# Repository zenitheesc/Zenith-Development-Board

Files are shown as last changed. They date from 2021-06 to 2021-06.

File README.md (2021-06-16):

<h1 align="center" style="color:white; background-color:black">Zenith Development Board</h1>
<h4 align="center">A Development Board based on STM32F103C8T6</h4>

<p align="center">
	<a href="http://zenith.eesc.usp.br/">
    
    </a>
    <a href="https://eesc.usp.br/">
    
    </a>
    <a href="https://github.com/${{ env.REPOSITORY_FULL_NAME }}/blob/main/LICENSE">
    
    </a>
    <a href="https://github.com/${{ env.REPOSITORY_FULL_NAME }}/issues">
    
    </a>
    <a href="https://github.com/${{ env.REPOSITORY_FULL_NAME }}/commits/main">
    
    </a>
    <a href="https://github.com/${{ env.REPOSITORY_FULL_NAME }}/graphs/contributors">
    
    </a>
    <a href="https://github.com/${{ env.REPOSITORY_FULL_NAME }}/commits/main">
    
    </a>
    <a href="https://github.com/${{ env.REPOSITORY_FULL_NAME }}/issues">
    
    </a>
    <a href="https://github.com/${{ env.REPOSITORY_FULL_NAME }}/pulls">
    
    </a>
</p>

<p align="center">
    <a href="#environment-and-tools">Environment and Tools</a> •
    <a href="#how-to-contribute">How to contribute?</a> 
</p>

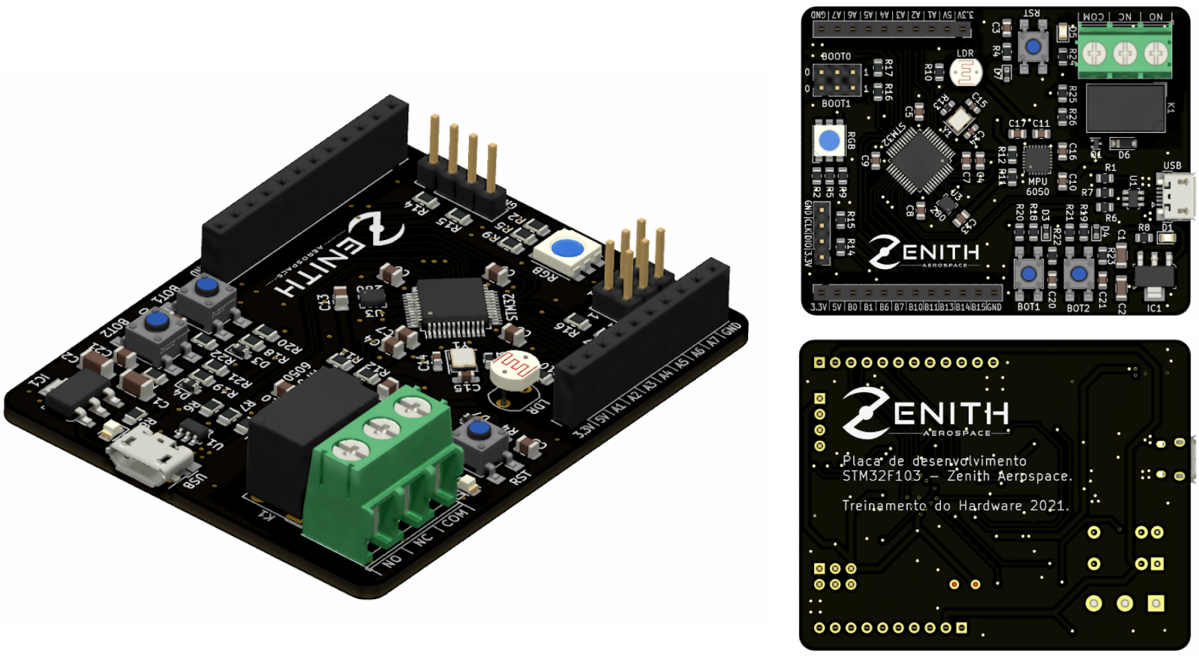
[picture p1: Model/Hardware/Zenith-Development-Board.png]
Zenith-Development-Board


## Environment and tools

This board was developed using [KiCad](https://www.kicad.org/) with native components.

## How to contribute

Fork your personal Git and add your hardware and software version in the "Development" folder following the Issues listed in the repository.

---

<p align="center">
    <a href="http://zenith.eesc.usp.br">
    
    </a> 
    <a href="https://www.facebook.com/zenitheesc">
    
    </a> 
    <a href="https://www.instagram.com/zenith_eesc/">
    
    </a>

</p>
<p align = "center">
<a href="zenith.eesc@gmail.com">zenith.eesc@gmail.com</a>
</p>

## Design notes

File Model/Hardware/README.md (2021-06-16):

# Zenith Development Board

Development board based on the STM32F103C8T6 developed to introduce the group members to circuits similar to those that can be used in the projects, including light, acceleration, rotation, pressure and temperature sensors, as well as actuators such as Mosfets, Relays and Leds.

# Schematic

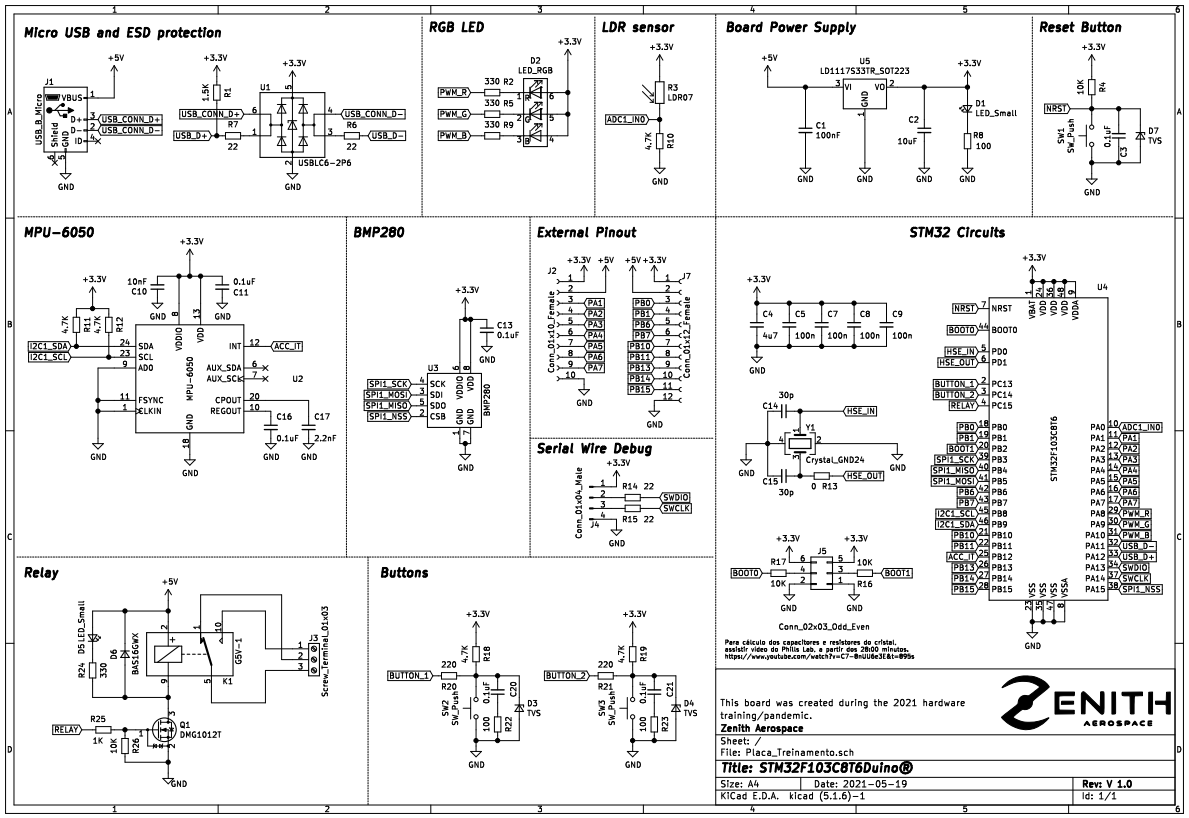
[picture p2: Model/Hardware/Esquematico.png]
Schematic


# Layout

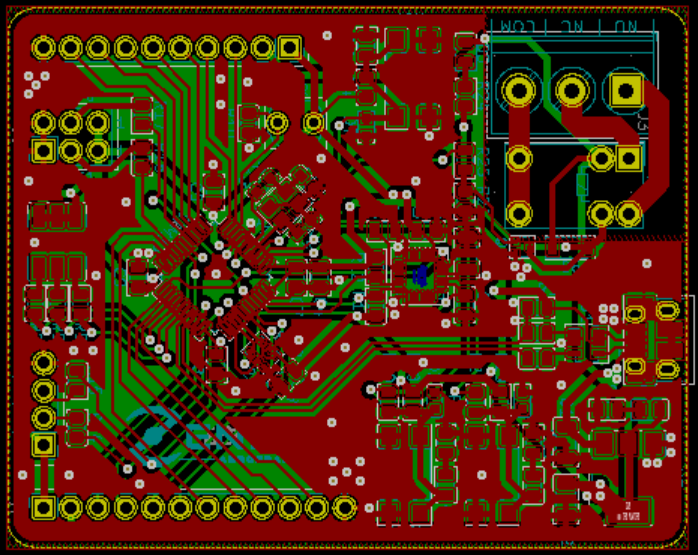
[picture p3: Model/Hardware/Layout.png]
Layout


# B.O.M.
|Component|Amount|Description|
|--|--|--|
|STM32F103C8T6|1|Microcontroller|
|Crystal|1|16MHz|
|MPU-6050|1|Accelerometer and Gyroscope|
|BMP280|1|Pressure and temperature sensor|
|LDR|1|Light Dependent Resistor|
|RGB-LED|1|Led SMD|
|Button|2|Push button|
|ESD suppressor|2|652-CGA0603MLC-12E|
|Micro USB|1|Micro USB connector|
|ESD Protection|1|USBLC6-4SC6Y|
|Linear regulator|1|LD1117S33TR|
|Rele|1|G5V-1-DC5|
|Mosfet|1|DMG1012T-7|

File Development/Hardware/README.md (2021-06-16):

# [Circuit name]

[Description]

# Schematic

[Figure]

# Layout

[Figure]

# Tests

## Simulation

[Description]

## Prototyping

[Description]

## Validation

[Description]

# B.O.M.
|Component|Amount|Description|
|--|--|--|
|X|0|x|
|Y|0|y|
|Z|0|z|

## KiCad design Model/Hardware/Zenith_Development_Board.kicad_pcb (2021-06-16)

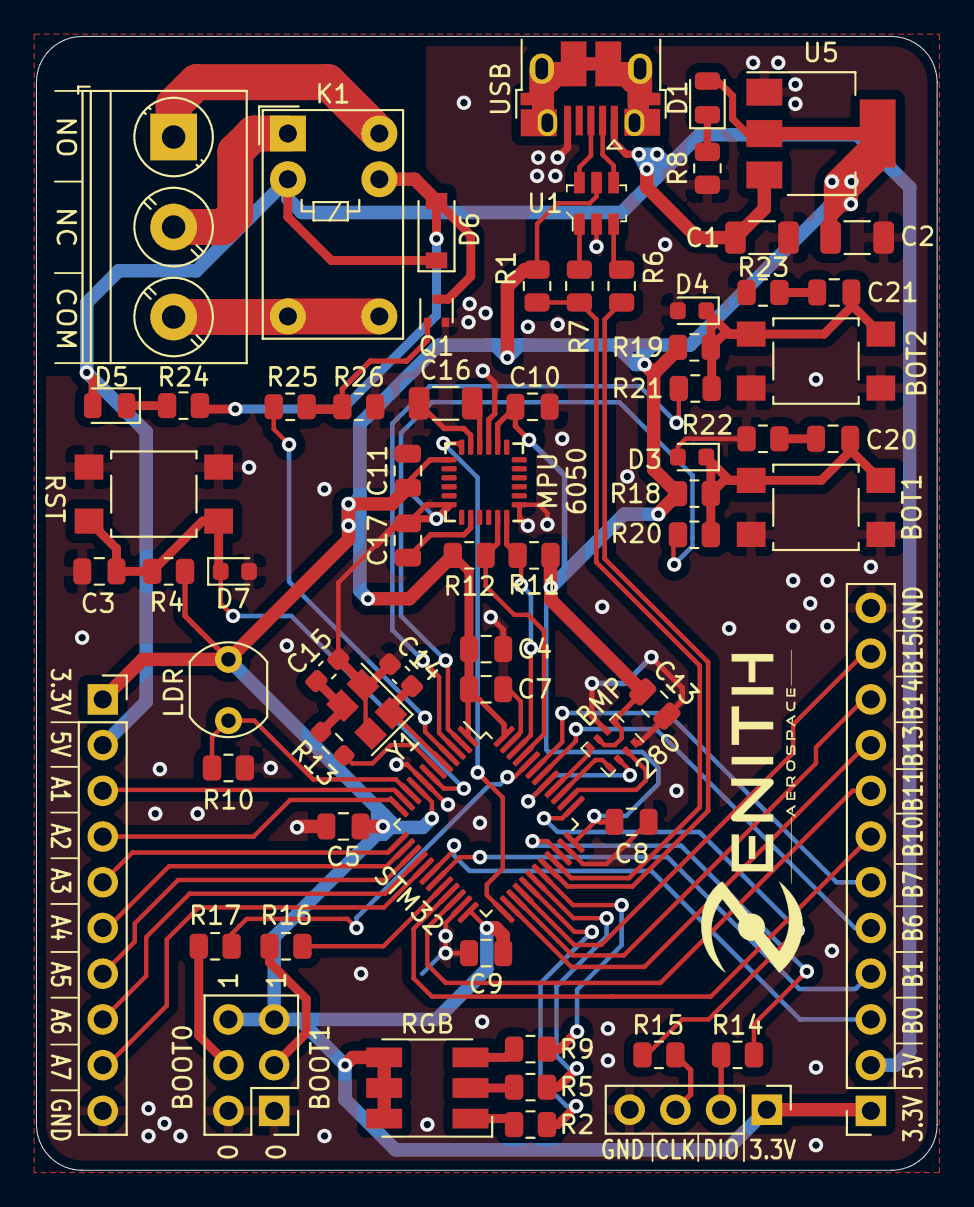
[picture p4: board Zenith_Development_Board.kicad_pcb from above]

Board: 2 copper layers, 50.0 x 63.0 mm, 67 parts (0 on the bottom side), 67 nets.

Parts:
C1: 100nF; C_1206_3216Metric
C2: 10uF; C_1206_3216Metric
C3, C11, C13, C20, C21: 0.1uF; C_0805_2012Metric
C4: 4u7; C_0805_2012Metric
C5, C7, C8, C9: 100n; C_0805_2012Metric
C10: 10nF; C_0805_2012Metric
C14, C15: 30p; C_0603_1608Metric_Pad1.08x0.95mm_HandSolder
C16: 0.1uF; C_1206_3216Metric
C17: 2.2nF; C_0805_2012Metric
D1, D5: LED_Small; LED_0805_2012Metric
D2: LED_RGB; LED_RGB_5050-6
D3, D4, D7: TVS; D_0603_1608Metric
D6: BAS16GWX; D_SOD-123
J1: USB_B_Micro; USB_Micro-B_Amphenol_10103594-0001LF_Horizontal
J2: Conn_01x10_Female; PinSocket_1x10_P2.54mm_Vertical
J3: Screw_Terminal_01x03; TerminalBlock_Phoenix_PT-1,5-3-5.0-H_1x03_P5.00mm_Horizontal
J4: Conn_01x04_Male; PinHeader_1x04_P2.54mm_Vertical
J5: Conn_02x03_Odd_Even; PinHeader_2x03_P2.54mm_Vertical
J7: Conn_01x12_Female; PinSocket_1x12_P2.54mm_Vertical
K1: G5V-1; Relay_SPDT_Omron_G5V-1
Q1: DMG1012T; SOT-523
R1: 1.5K; R_0805_2012Metric
R2, R5, R9, R24: 330; R_0805_2012Metric
R3: LDR07; R_LDR_5.1x4.3mm_P3.4mm_Vertical
R4, R16, R17, R26: 10K; R_0805_2012Metric
R6, R7, R14, R15: 22; R_0805_2012Metric
R8, R22, R23: 100; R_0805_2012Metric
R10, R11, R12, R18, R19: 4.7K; R_0805_2012Metric
R13: 0; R_0603_1608Metric_Pad0.98x0.95mm_HandSolder
R20, R21: 220; R_0805_2012Metric
R25: 1K; R_0805_2012Metric
SW1, SW2, SW3: SW_Push; SW_SPST_TL3305A
U1: USBLC6-2P6; SOT23-6L
U2: MPU-6050; InvenSense_QFN-24_4x4mm_P0.5mm
U3: BMP280; Bosch_LGA-8_2x2.5mm_P0.65mm_ClockwisePinNumbering
U4: STM32F103C8T6; LQFP-48_7x7mm_P0.5mm
U5: LD1117S33TR_SOT223; SOT-223-3_TabPin2
Y1: Crystal_GND24; Crystal_SMD_SeikoEpson_FA238-4Pin_3.2x2.5mm

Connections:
+3V3: C2.1, C4.1, C5.1, C7.1, C8.1, C9.1, C10.2, C11.1, C13.1, D1.2, D2.4, D2.5, D2.6, J2.1, J4.1, J5.5, J5.6, J7.1, R1.2, R3.1, R4.1, R11.1, R12.1, R18.1, R19.1, U1.5, U2.8, U2.13, U3.6, U3.8, U4.1, U4.9, U4.24, U4.36, U4.48, U5.2
+5V: C1.1, D5.2, D6.1, J1.1, J2.2, J7.2, K1.2, U5.3
ACC_IT: U2.12, U4.25
ADC1_IN0: R3.2, R10.1, U4.10
BOOT0: R17.1, U4.44
BOOT1: R16.1, U4.20
BUTTON_1: R20.2, U4.2
BUTTON_2: R21.2, U4.3
GND: C1.2, C2.2, C3.1, C4.2, C5.2, C7.2, C8.2, C9.2, C10.1, C11.2, C13.2, C14.2, C15.2, C16.2, C17.2, D3.2, D4.2, D7.2, J1.5, J2.10, J4.4, J5.1, J5.2, J7.12, Q1.2, R8.1, R10.2, R22.2, R23.2, R26.2, SW1.2, SW2.2, SW3.2, U1.2, U2.1, U2.9, U2.11, U2.18, U3.1, U3.7, U4.8, U4.23, U4.35, U4.47, U5.1, Y1.2, Y1.4
HSE_IN: C14.1, U4.5, Y1.1
HSE_OUT: R13.2, U4.6
I2C1_SCL: R12.2, U2.23, U4.45
I2C1_SDA: R11.2, U2.24, U4.46
NRST: C3.2, D7.1, R4.2, SW1.1, U4.7
unnamed: C15.1, R13.1, Y1.3
unnamed: C16.1, U2.10
unnamed: C17.1, U2.20
unnamed: C20.1, R22.1
unnamed: C20.2, D3.1, R18.2, R20.1, SW2.1
unnamed: C21.1, R23.1
unnamed: C21.2, D4.1, R19.2, R21.1, SW3.1
unnamed: D1.1, R8.2
unnamed: D2.1, R2.1
unnamed: D2.2, R5.1
unnamed: D2.3, R9.1
unnamed: D5.1, R24.2
unnamed: D6.2, K1.9, Q1.3, R24.1
unnamed: J3.1, K1.10
unnamed: J3.2, K1.1
unnamed: J3.3, K1.5, K1.6
unnamed: J4.2, R14.1
unnamed: J4.3, R15.1
unnamed: J5.3, R16.2
unnamed: J5.4, R17.2
unnamed: Q1.1, R25.1, R26.1
unnamed: R6.1, U1.3
unnamed: R7.2, U1.1
PA1: J2.3, U4.11
PA2: J2.4, U4.12
PA3: J2.5, U4.13
PA4: J2.6, U4.14
PA5: J2.7, U4.15
PA6: J2.8, U4.16
PA7: J2.9, U4.17
PB0: J7.3, U4.18
PB1: J7.4, U4.19
PB6: J7.5, U4.42
PB7: J7.6, U4.43
PB10: J7.7, U4.21
PB11: J7.8, U4.22
PB13: J7.9, U4.26
PB14: J7.10, U4.27
PB15: J7.11, U4.28
PWM_B: R9.2, U4.31
PWM_G: R5.2, U4.30
PWM_R: R2.2, U4.29
RELAY: R25.2, U4.4
SPI1_MISO: U3.5, U4.40
SPI1_MOSI: U3.3, U4.41
SPI1_NSS: U3.2, U4.38
SPI1_SCK: U3.4, U4.39
SWCLK: R15.2, U4.37
SWDIO: R14.2, U4.34
USB_CONN_D+: J1.3, U1.6
USB_CONN_D-: J1.2, U1.4
USB_D+: R1.1, R7.1, U4.33
USB_D-: R6.2, U4.32
